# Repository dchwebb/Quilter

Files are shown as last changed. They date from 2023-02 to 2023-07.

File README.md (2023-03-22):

# Quilter
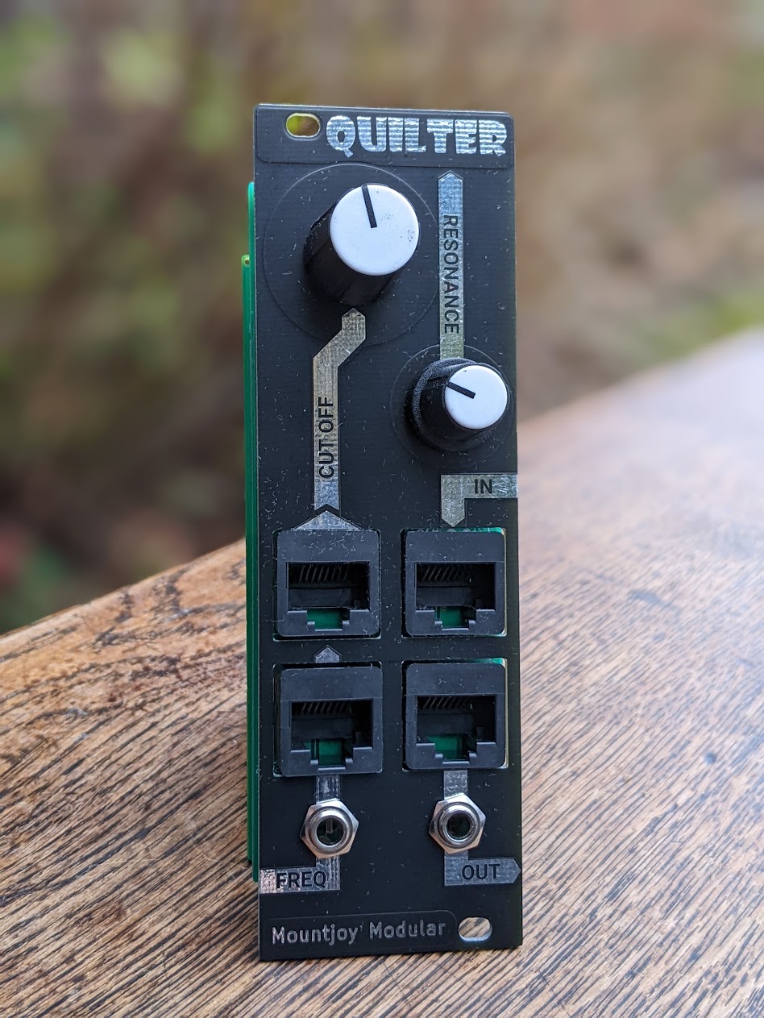
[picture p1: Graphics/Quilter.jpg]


Quilter
--------

Quilter is a four-voice polyphonic analog low pass filter designed for use with the Eurorack Modular Synthesiser architecture.

As part of a range of compatilble Mountjoy Modular modules, polyphonic interconnections are made using RJ-45 cables (as used for Ethernet).

Each of the four filters is a four-pole self-oscillating low pass filter. Cutoff is controlled by a combination of shared signals (frequency potentiometer and jack socket) and two individual  controls frequency controls (one at approximately half the sensitivity of the other) available on RJ-45 connectors.

Resonance is controlled from a potentiometer with self-oscillation available at extreme settings.

Polyphonic output is available from an RJ-45 socket and a mixed output is available on a 3.5mm jack socket.

The module is built around the Sound Semiconductor SSI2144 Fatkeys Four-Pole Voltage Controlled Filter. A number of TL074/TL072 op-amps are used for control signal mixing, buffering and output amplification.

Two trimmer potentiometers are available for each voice to control volt per octave when using the filter in self-resonant mode, and frequency offset to control the base frequency of the cut-off of each voice.

Technical
---------

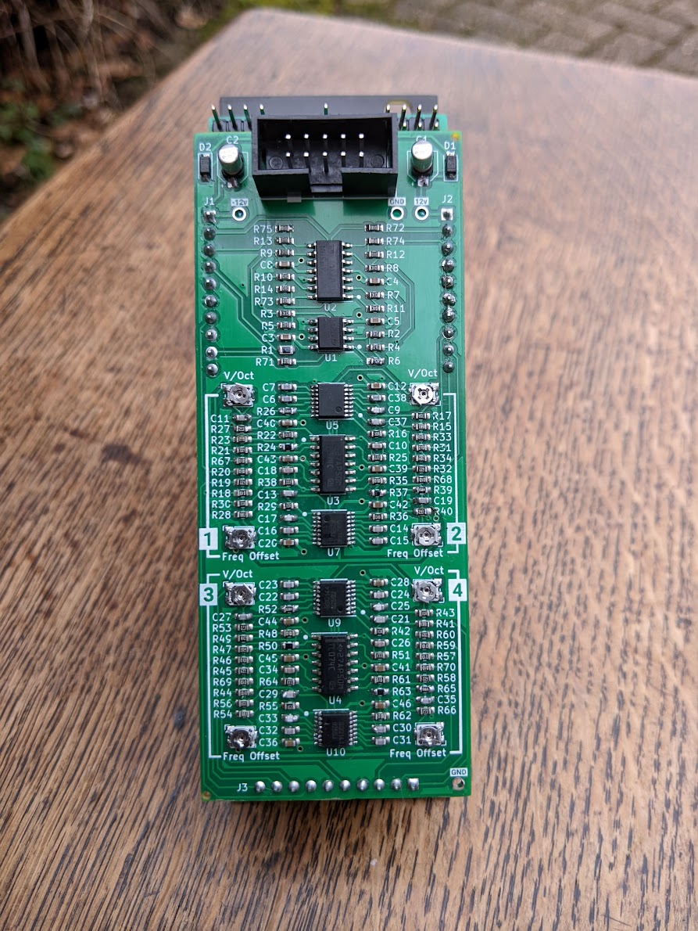
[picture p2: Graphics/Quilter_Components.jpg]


Construction is a sandwich of three PCBs with a component board, a controls board and a panel. PCBs designed in Kicad v6.

[Components schematic](https://raw.githubusercontent.com/dchwebb/Quilter/master/Quilter_Components.pdf)

[Controls schematic](https://raw.githubusercontent.com/dchwebb/Quilter/master/Quilter_Controls.pdf)

### Power

The Eurorack +/-12V rails have reverse polarity protection and filtering.

- +12V Current Draw: 52mA
- -12V Current Draw: 50mA

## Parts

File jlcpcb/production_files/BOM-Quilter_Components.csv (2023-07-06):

Comment | Designator | Footprint | LCSC
100pF | C10,C18,C26,C34 | C_0603_1608Metric_Pad1.08x0.95mm_HandSolder | C14858
1uF | C12,C20,C28,C3,C36,C39,C4,C40,C41,C42,C43,C44,C45,C46,C5,C8 | C_0603_1608Metric_Pad1.08x0.95mm_HandSolder | C15849
3.3nF | C13,C21,C29,C37 | C_0603_1608Metric_Pad1.08x0.95mm_HandSolder | C1613
6.8nF_C0G | C14,C15,C16,C22,C23,C24,C30,C31,C32,C38,C6,C7 | C_0603_1608Metric_Pad1.08x0.95mm_HandSolder | C162241
10uF | C47,C48,C49,C50 | C_0603_1608Metric_Pad1.08x0.95mm_HandSolder | C19702
1k | R23,R36,R49,R62,R71,R72,R73,R74,R75 | R_0603_1608Metric_Pad0.98x0.95mm_HandSolder | C21190
160k | R21,R34,R47,R60 | R_0603_1608Metric_Pad0.98x0.95mm_HandSolder | C22813
220k | R19,R32,R45,R58 | R_0603_1608Metric_Pad0.98x0.95mm_HandSolder | C22961
4.7k | R6 | R_0603_1608Metric_Pad0.98x0.95mm_HandSolder | C23162
68k | R15,R28,R41,R54 | R_0603_1608Metric_Pad0.98x0.95mm_HandSolder | C23231
24k | R27,R40,R53,R66 | R_0603_1608Metric_Pad0.98x0.95mm_HandSolder | C23352
100k | R18,R20,R22,R31,R33,R35,R44,R46,R48,R57,R59,R61,R67,R68,R69,R70 | R_0603_1608Metric_Pad0.98x0.95mm_HandSolder | C25803
10k | R10,R11,R12,R13,R14,R2,R3,R4,R5,R7,R8,R9 | R_0603_1608Metric_Pad0.98x0.95mm_HandSolder | C25804
33k | R25,R38,R51,R64 | R_0603_1608Metric_Pad0.98x0.95mm_HandSolder | C4216
10nF | C11,C19,C27,C35 | C_0603_1608Metric_Pad1.08x0.95mm_HandSolder | C57112
TL072 | U1 | SO-8_3.9x4.9mm_P1.27mm | C6961
200 | R16,R17,R29,R30,R42,R43,R55,R56 | R_0603_1608Metric_Pad0.98x0.95mm_HandSolder | C8218
1N5819 | D1,D2 | D_SOD-123 | C8598

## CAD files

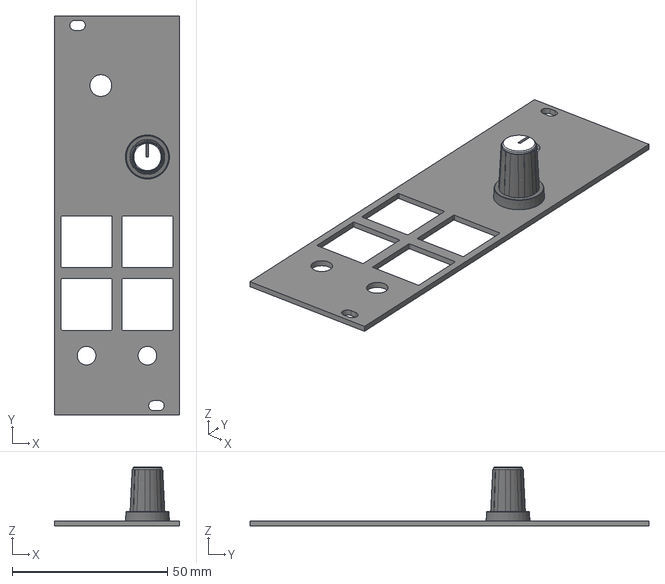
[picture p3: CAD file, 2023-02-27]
Graphics/Quilter_Panel.step
40.4 x 128.5 x 18.9 mm
_autosave-Quilter_Panel PCB

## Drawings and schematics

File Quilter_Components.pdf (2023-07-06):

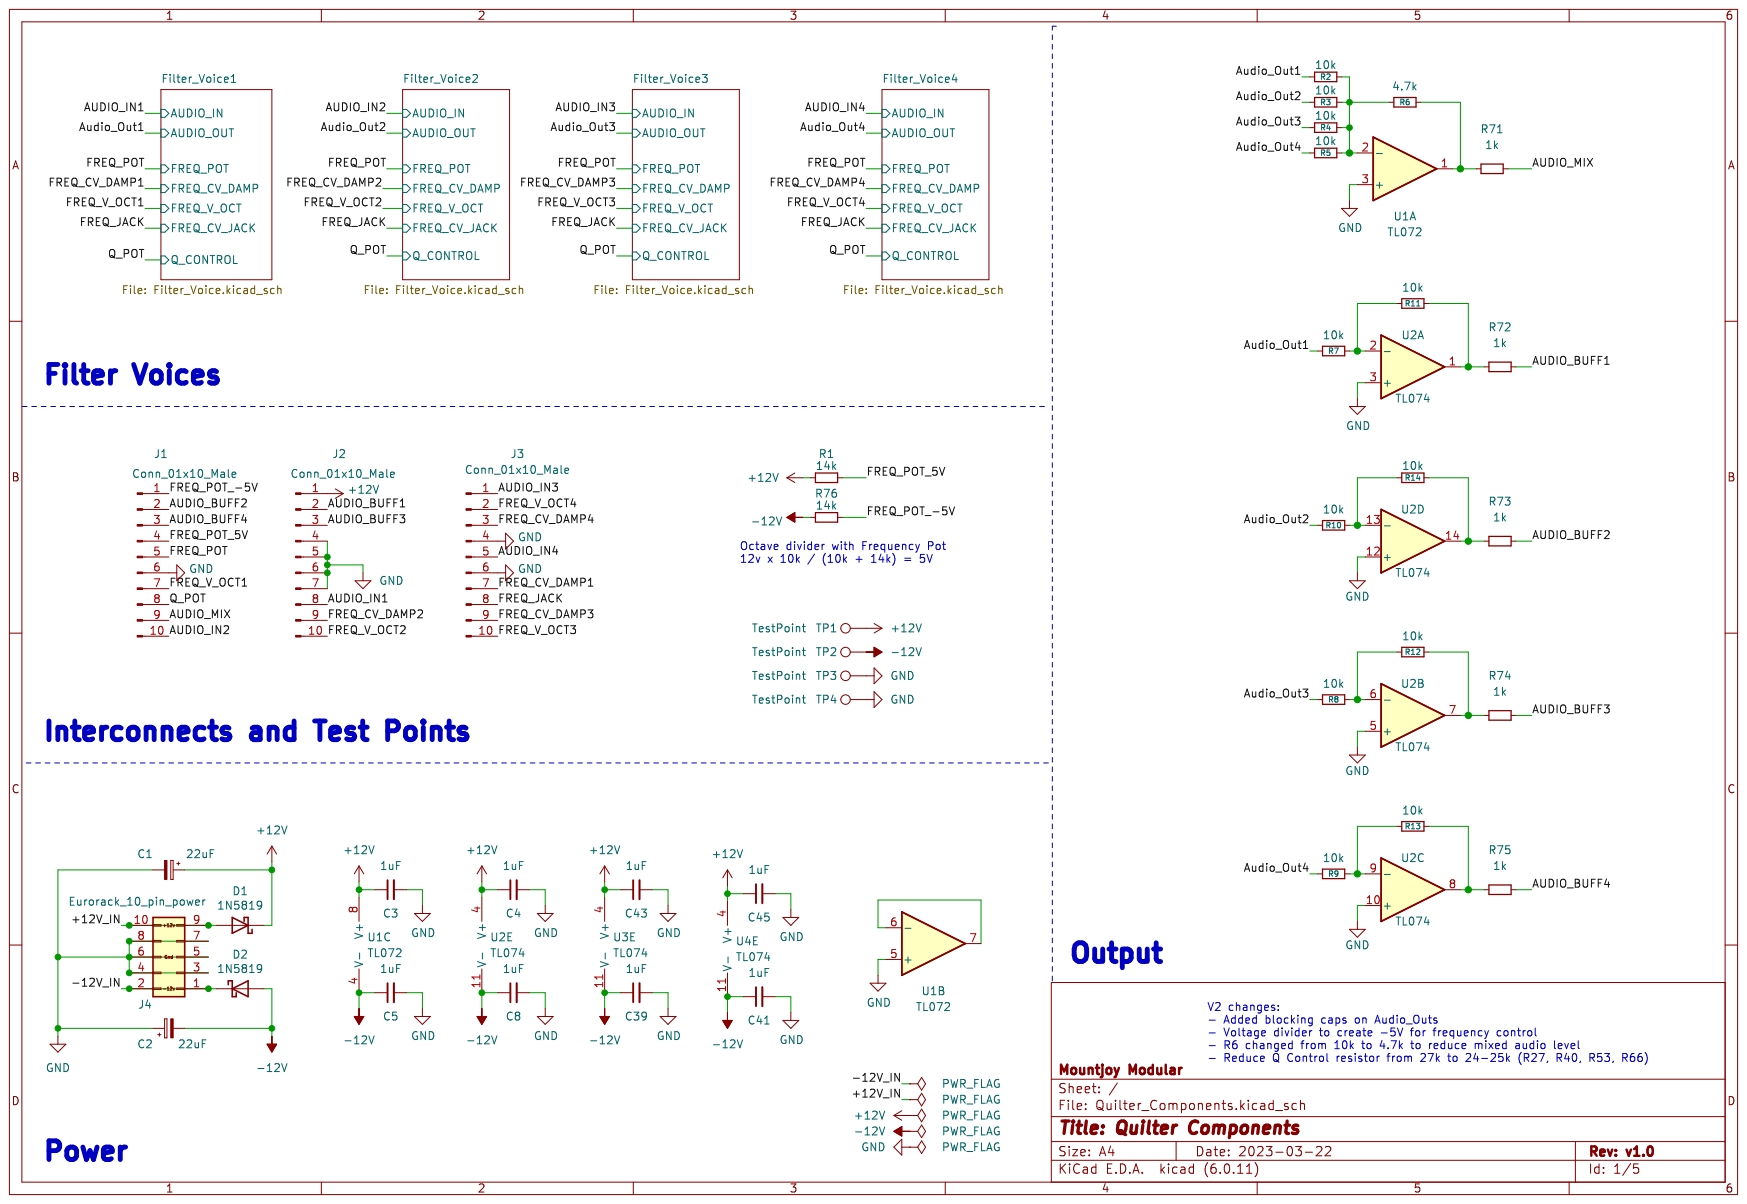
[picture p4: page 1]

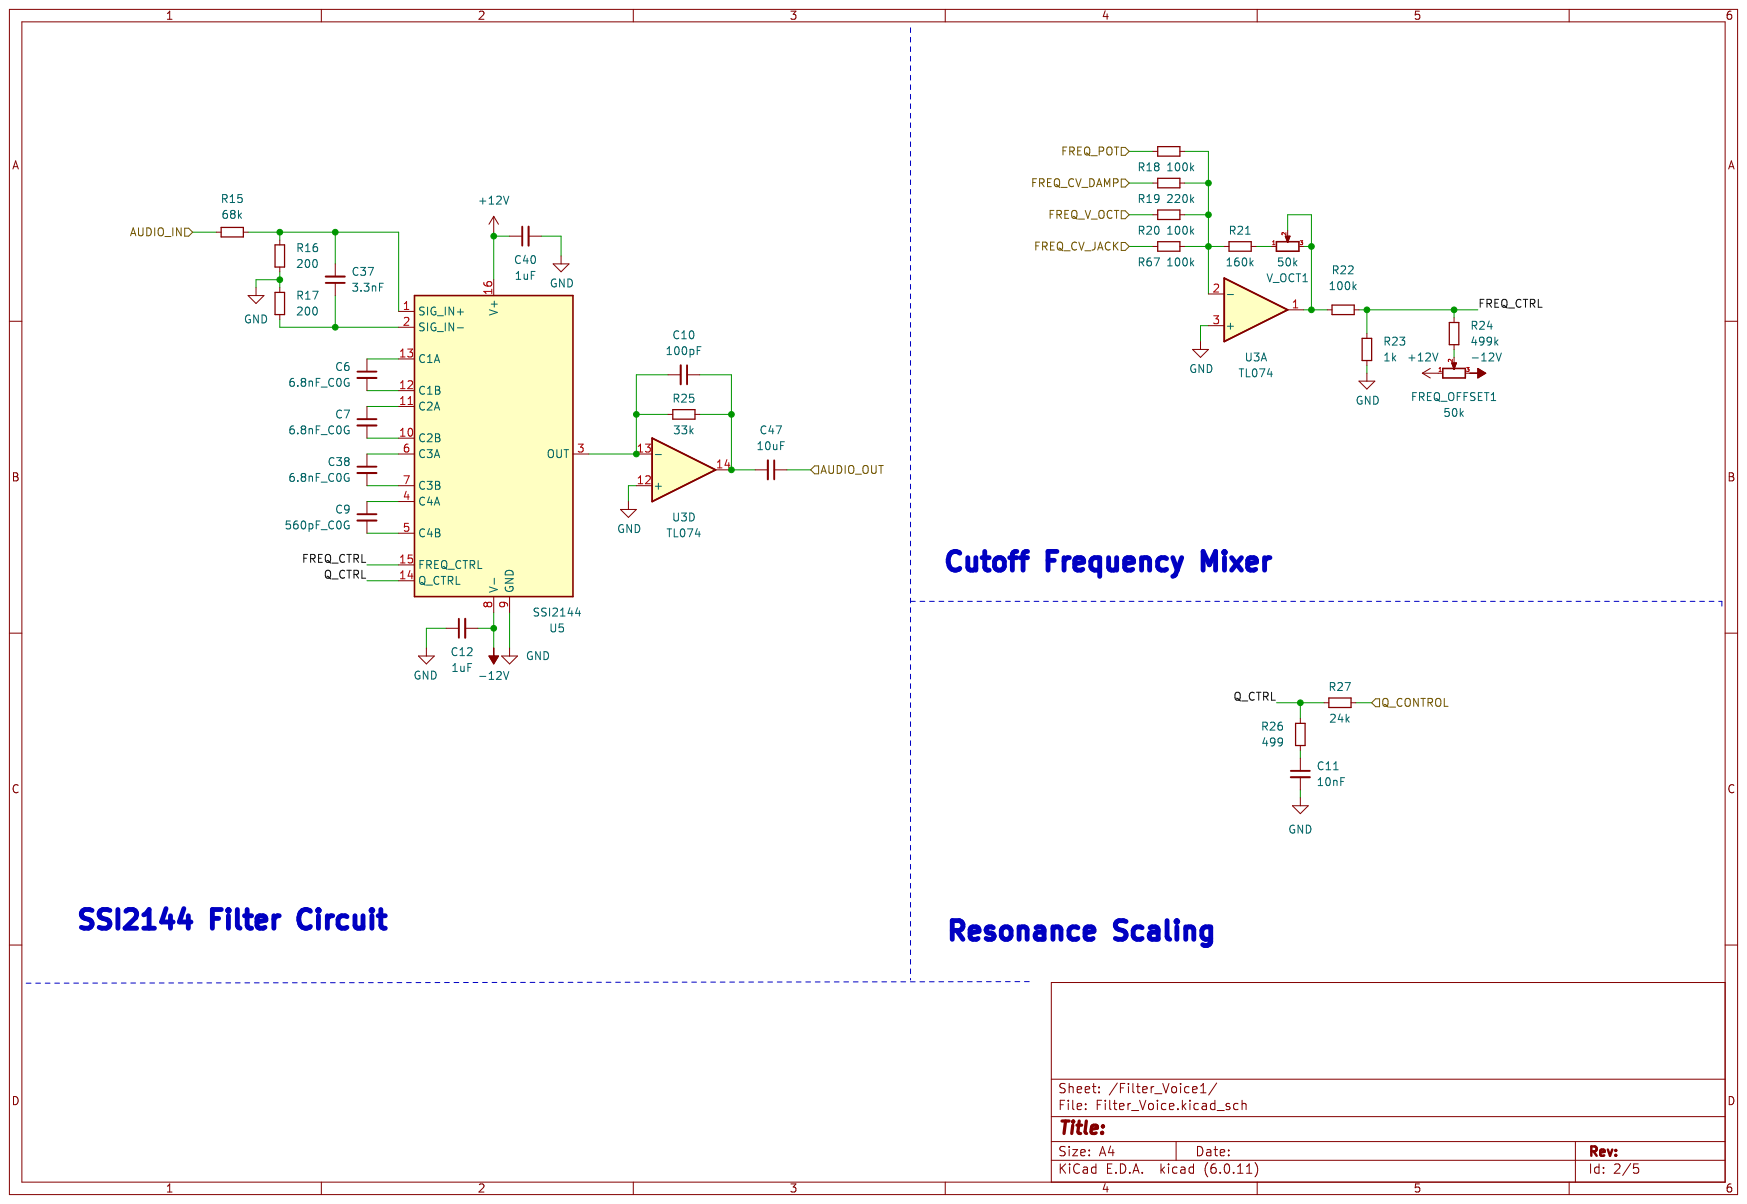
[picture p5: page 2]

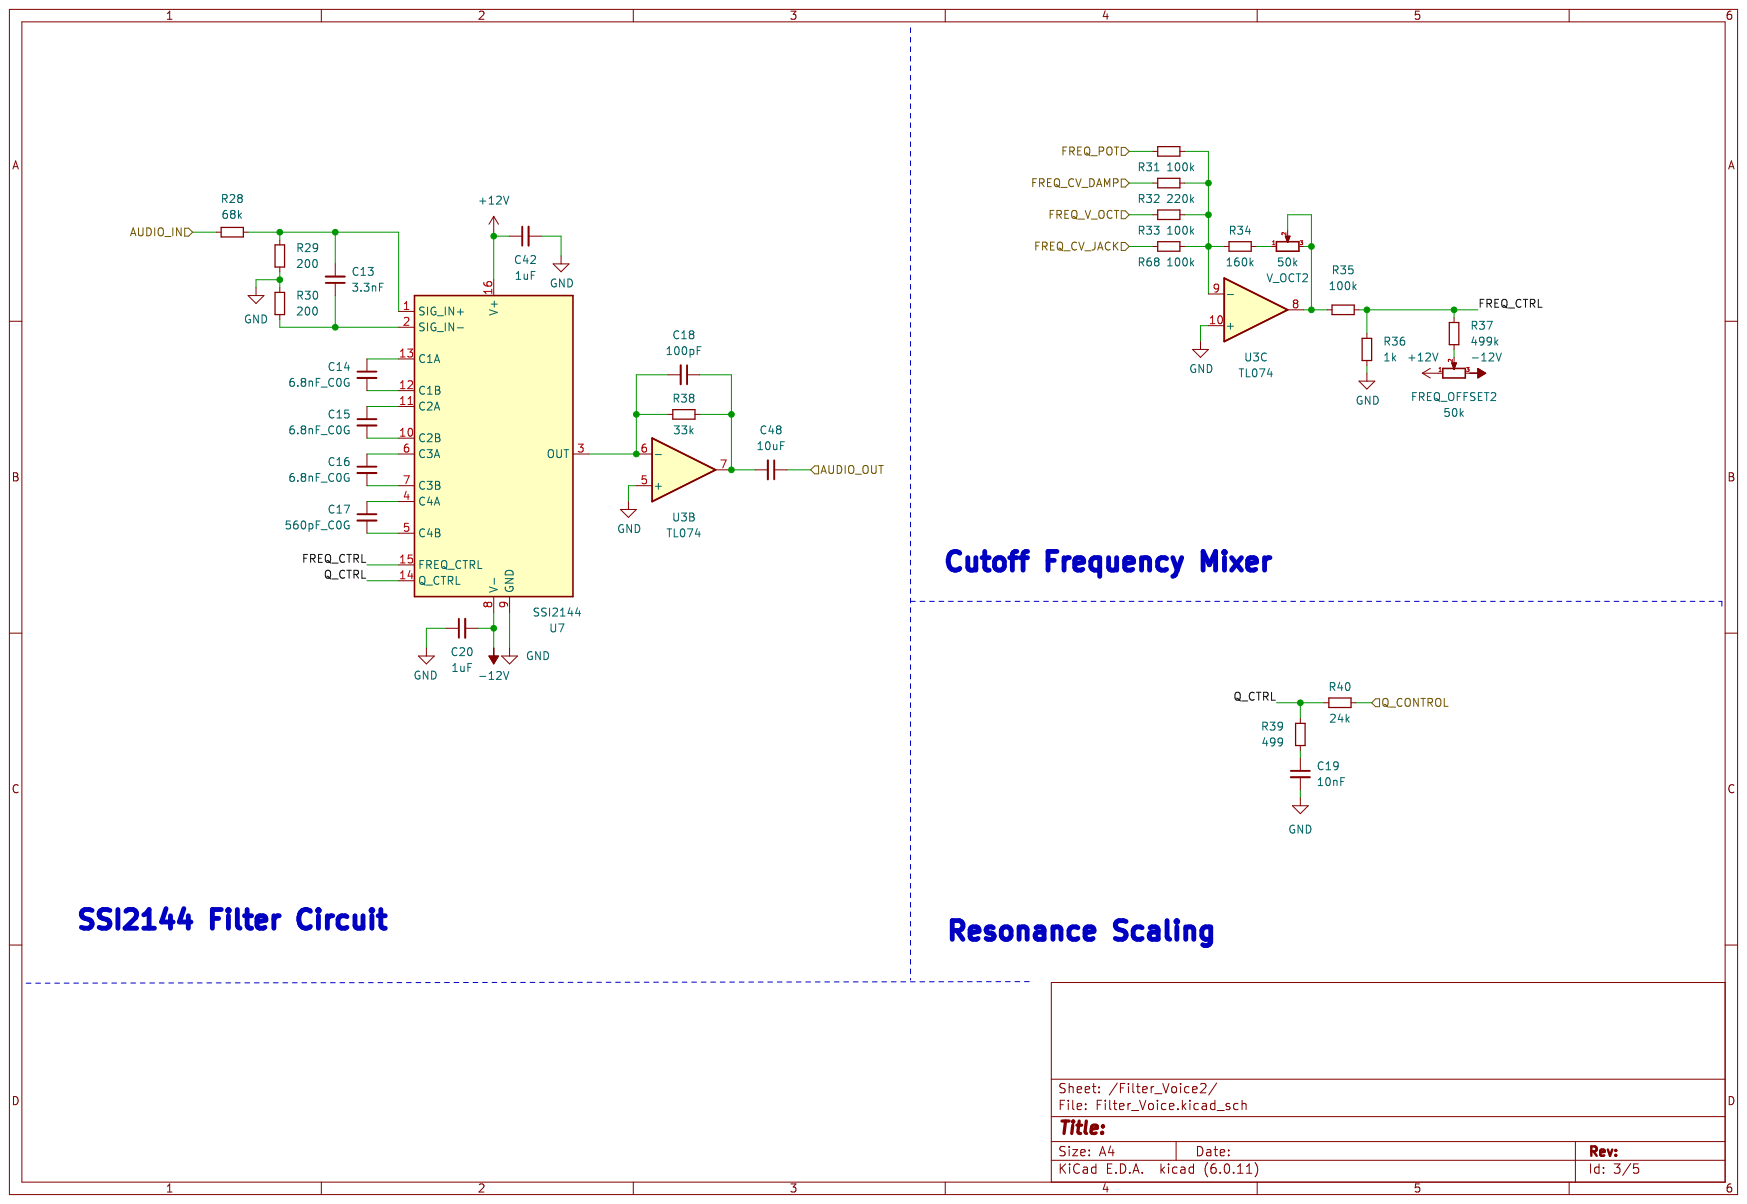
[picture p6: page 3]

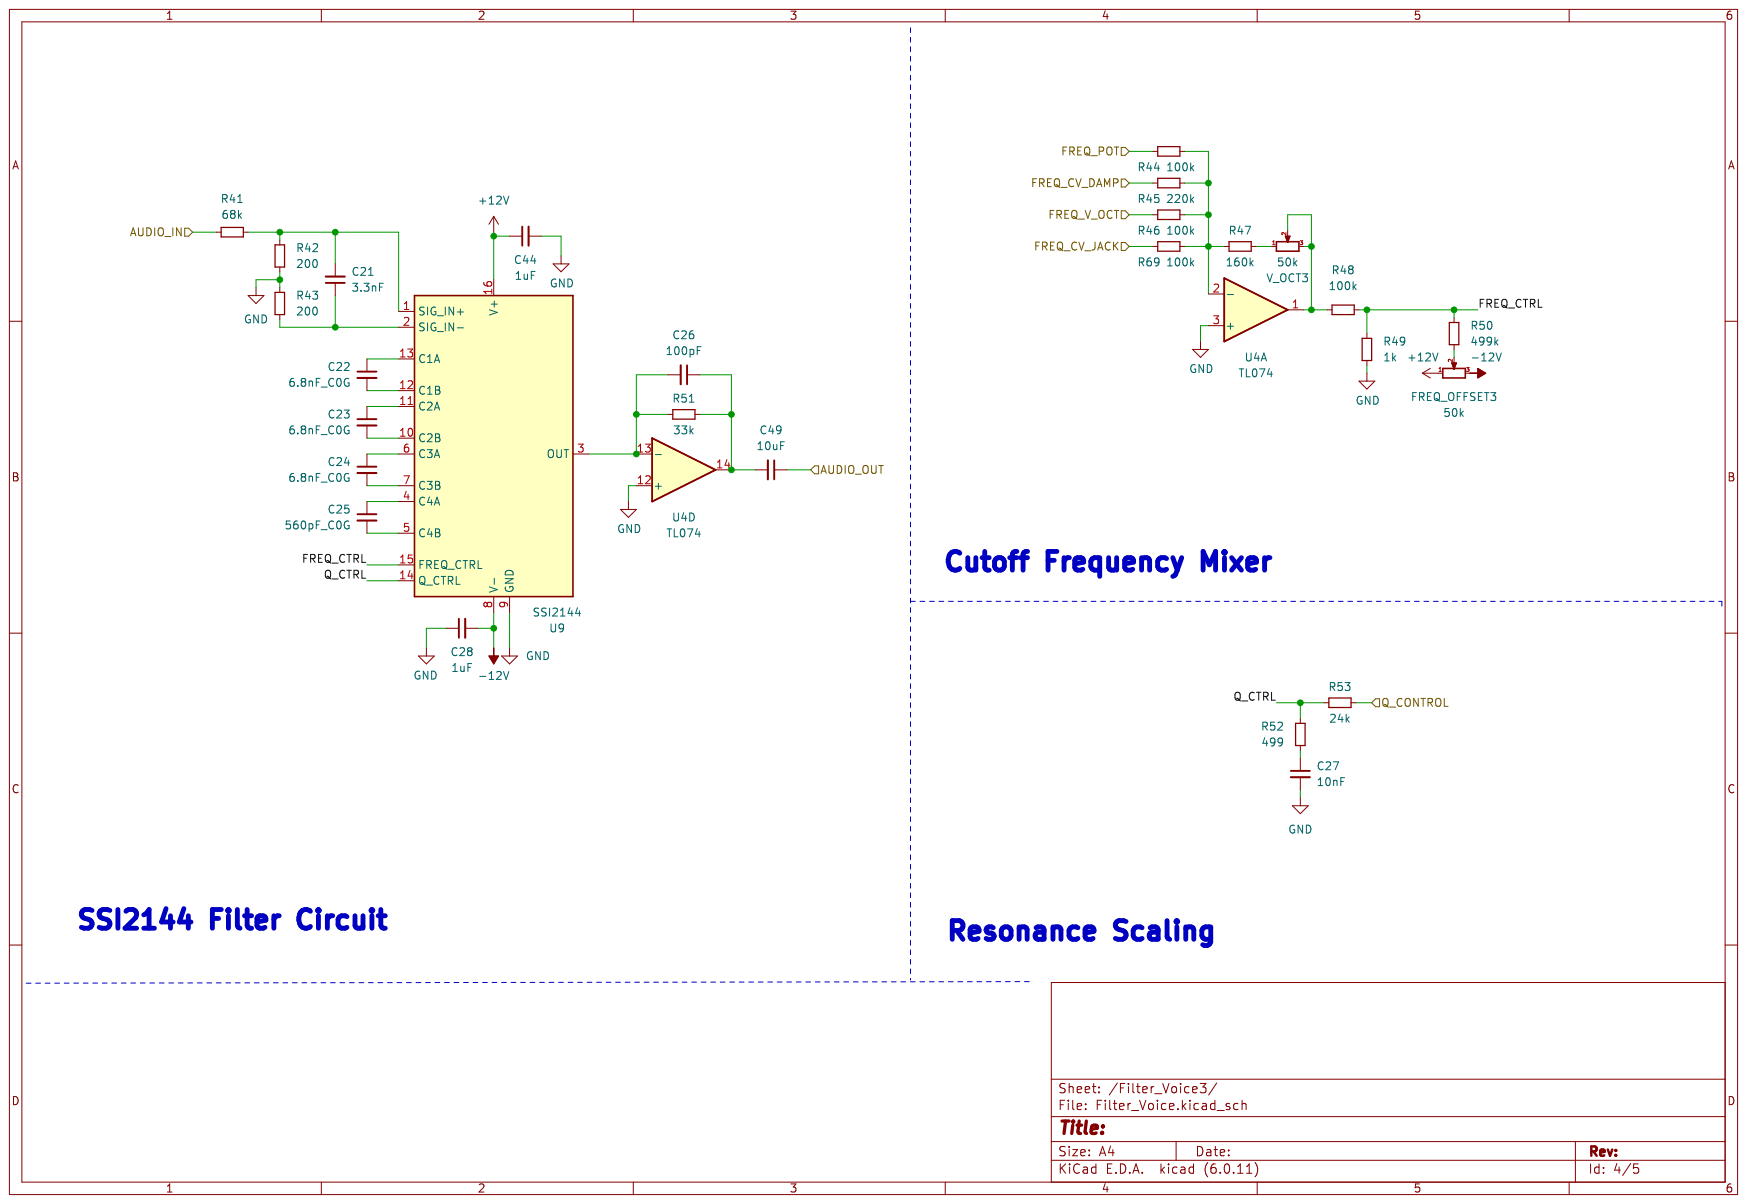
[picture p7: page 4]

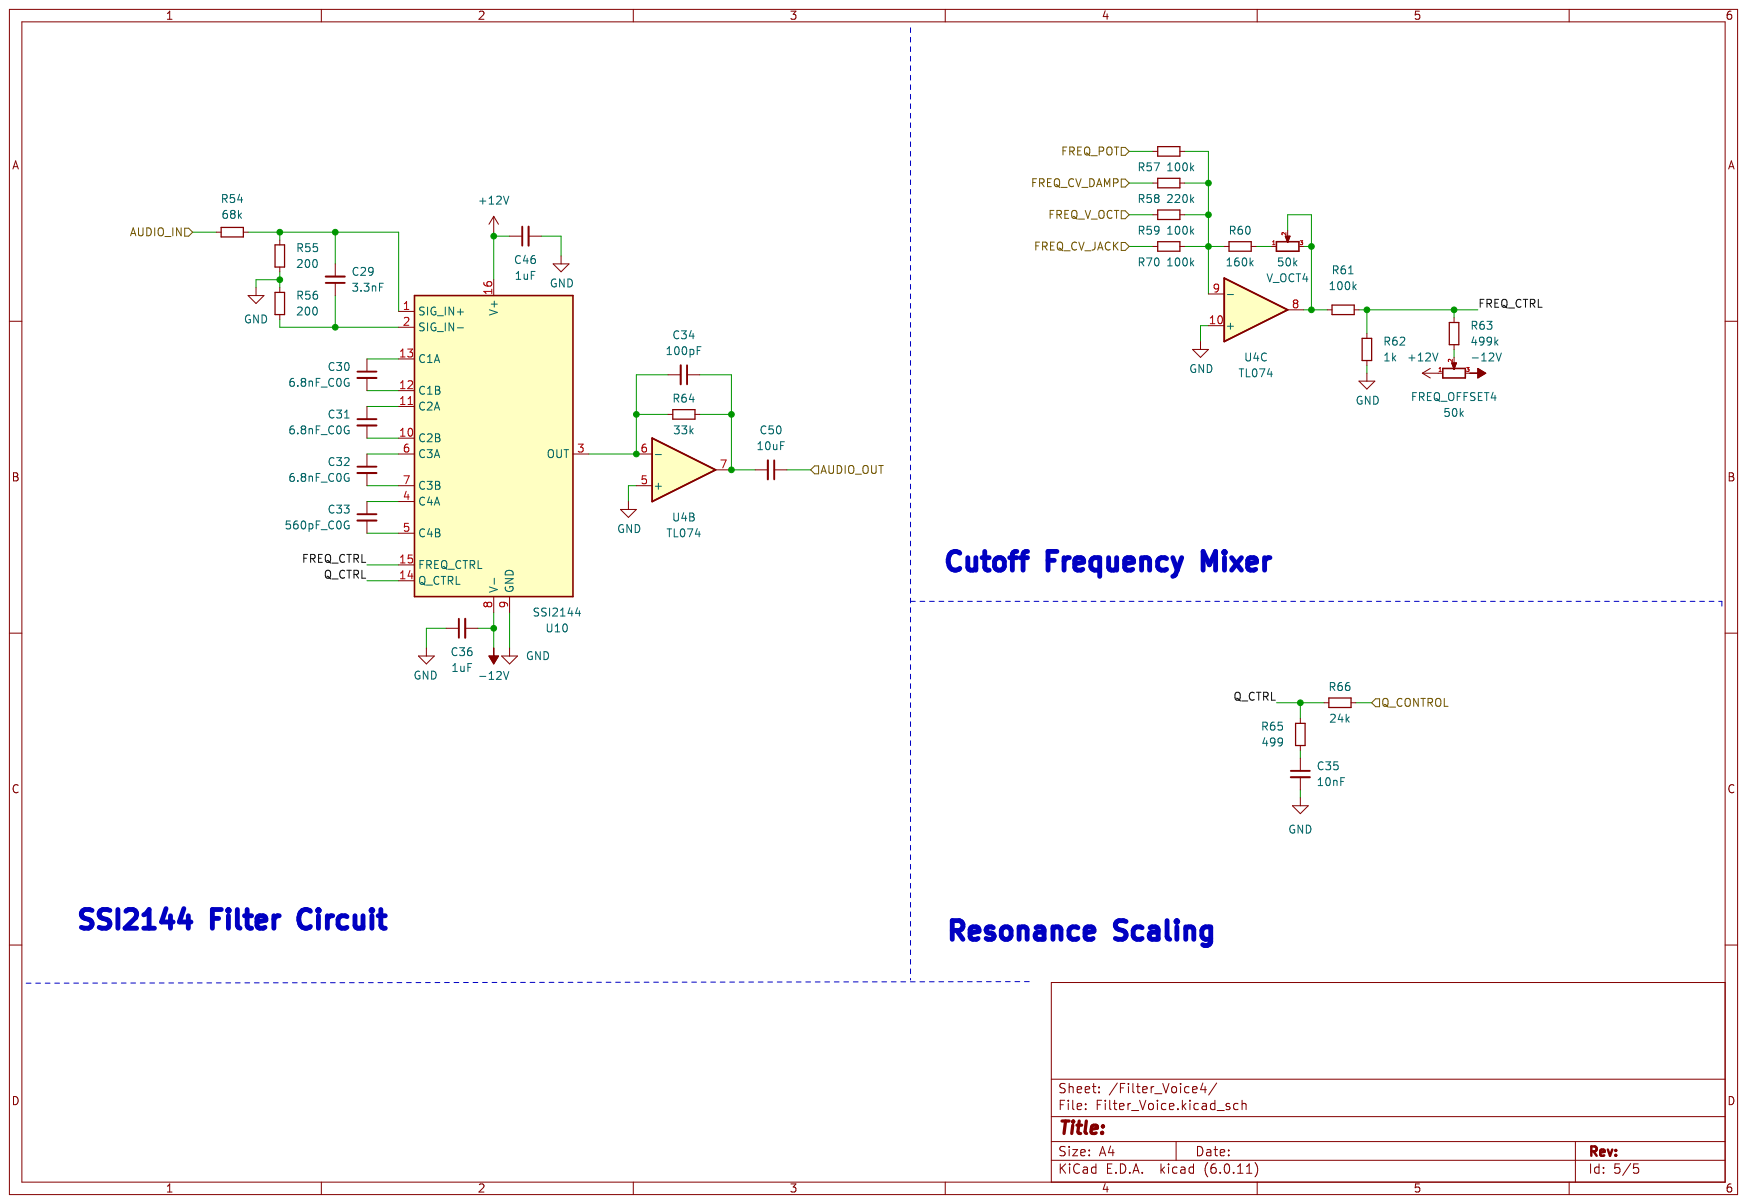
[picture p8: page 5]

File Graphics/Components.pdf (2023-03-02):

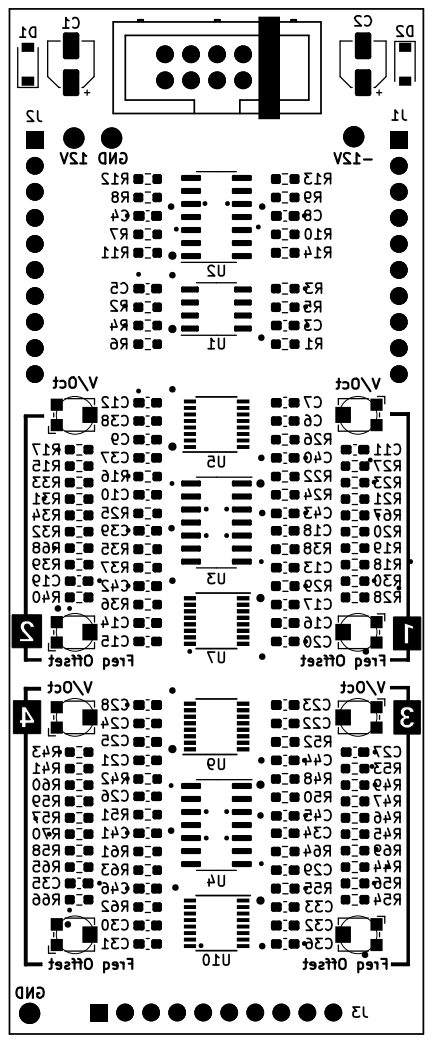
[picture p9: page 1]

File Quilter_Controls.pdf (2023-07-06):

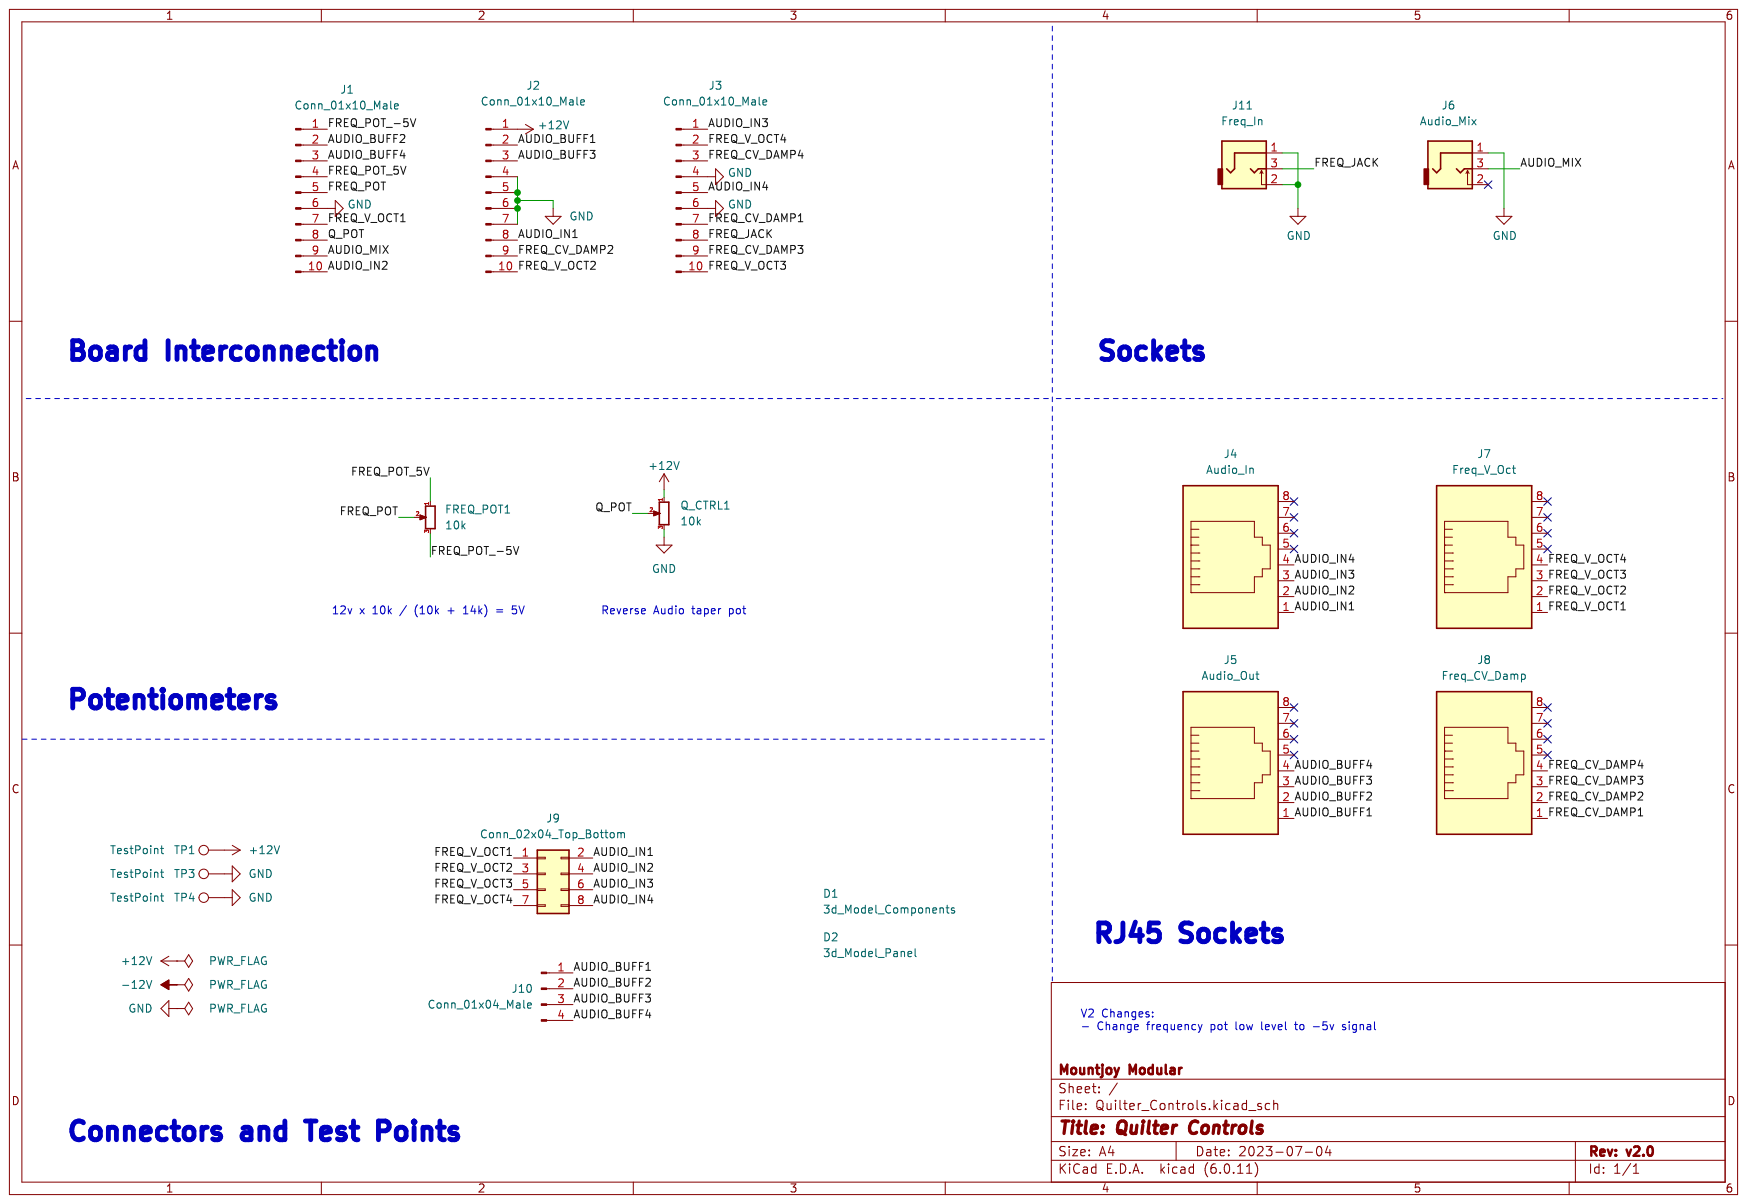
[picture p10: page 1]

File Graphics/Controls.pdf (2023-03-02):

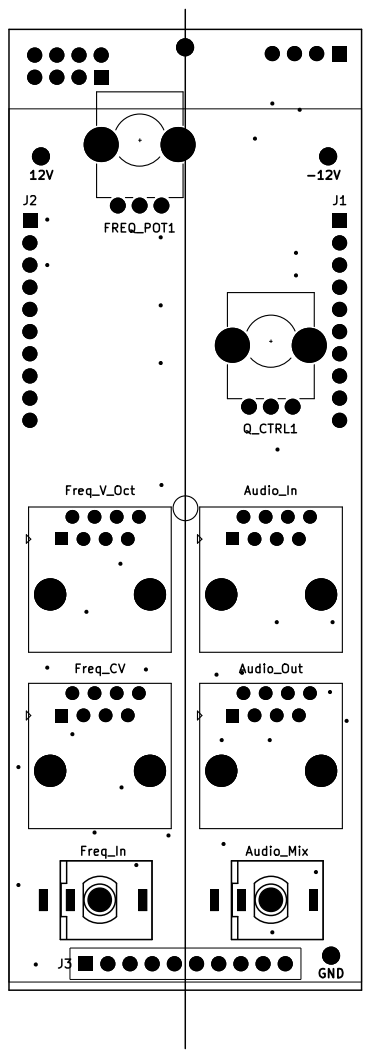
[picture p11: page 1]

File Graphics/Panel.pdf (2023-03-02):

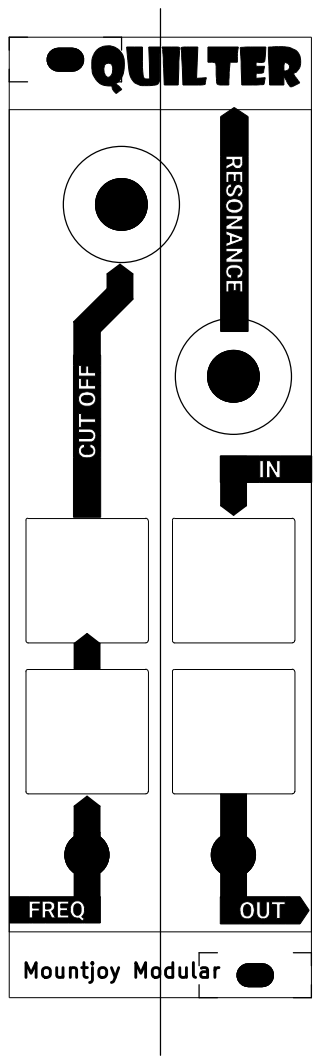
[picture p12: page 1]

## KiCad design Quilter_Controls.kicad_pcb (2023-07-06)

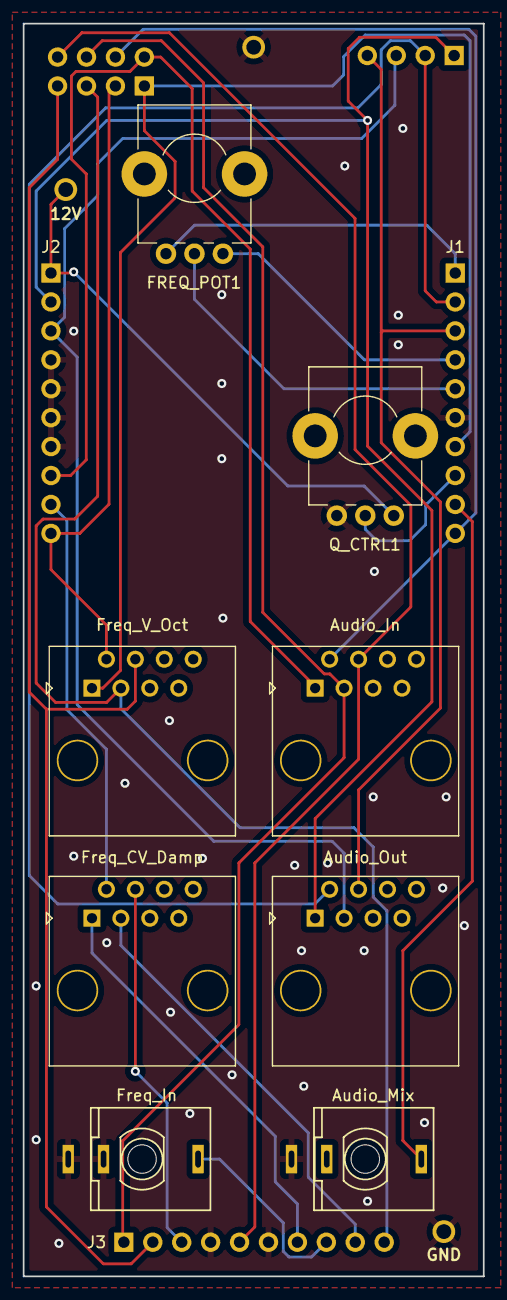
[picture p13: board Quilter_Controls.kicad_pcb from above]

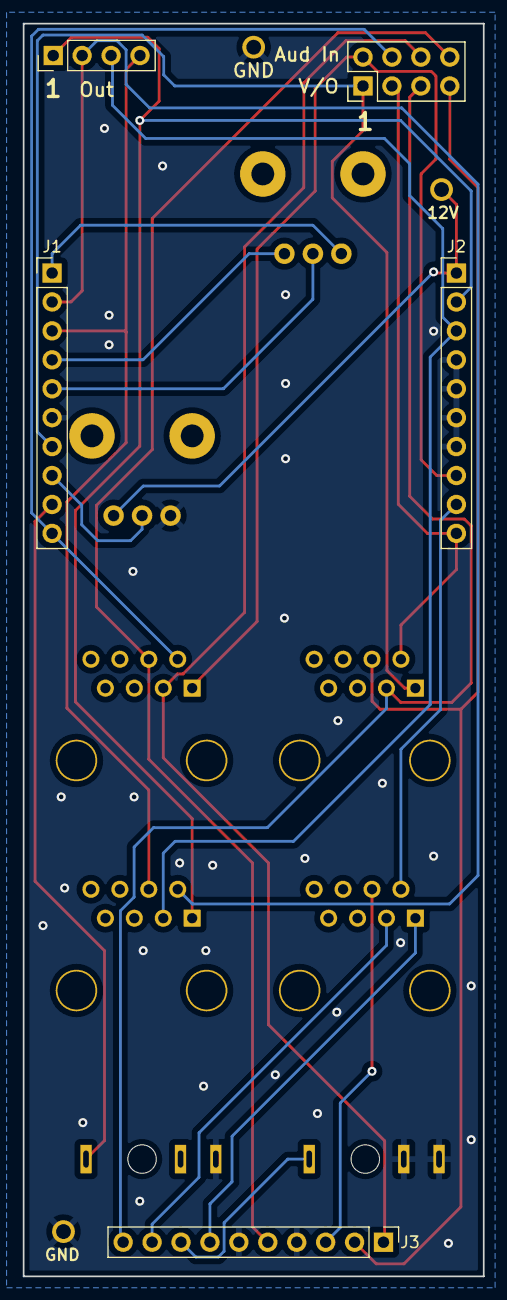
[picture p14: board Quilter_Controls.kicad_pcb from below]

Board: 2 copper layers, 40.4 x 110.0 mm, 16 parts (5 on the bottom side), 24 nets.

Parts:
FREQ_POT1: 10k; Alpha_9mm_Potentiometer_Aligned
J1, J2, J3: Conn_01x10_Male; PinHeader_1x10_P2.54mm_Vertical
J4: Audio_In; RJ45_Molex_42878-8506
J5: Audio_Out; RJ45_Molex_42878-8506
J6: Audio_Mix; THONKICONN_hole
J7: Freq_V_Oct; RJ45_Molex_42878-8506
J8: Freq_CV_Damp; RJ45_Molex_42878-8506
J9: Conn_02x04_Top_Bottom; PinHeader_2x04_P2.54mm_Vertical
J10: Conn_01x04_Male; PinHeader_1x04_P2.54mm_Vertical
J11: Freq_In; THONKICONN_hole
Q_CTRL1: 10k; Alpha_9mm_Potentiometer_Aligned
TP1, TP3, TP4: TestPoint; 1.3mm_Test_Point

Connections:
+12V: J2.1, Q_CTRL1.1, TP1.1
/AUDIO_BUFF1: J2.2, J5.1, J10.1
/AUDIO_BUFF2: J1.2, J5.2, J10.2
/AUDIO_BUFF3: J2.3, J5.3, J10.3
/AUDIO_BUFF4: J1.3, J5.4, J10.4
/AUDIO_IN1: J2.8, J4.1, J9.2
/AUDIO_IN2: J1.10, J4.2, J9.4
/AUDIO_IN3: J3.1, J4.3, J9.6
/AUDIO_IN4: J3.5, J4.4, J9.8
/AUDIO_MIX: J1.9, J6.3
/FREQ_CV_DAMP1: J3.7, J8.1
/FREQ_CV_DAMP2: J2.9, J8.2
/FREQ_CV_DAMP3: J3.9, J8.3
/FREQ_CV_DAMP4: J3.3, J8.4
/FREQ_JACK: J3.8, J11.3
/FREQ_POT: FREQ_POT1.2, J1.5
/FREQ_POT_5V: FREQ_POT1.1, J1.4
/FREQ_POT_-5V: FREQ_POT1.3, J1.1
/FREQ_V_OCT1: J1.7, J7.1, J9.1
/FREQ_V_OCT2: J2.10, J7.2, J9.3
/FREQ_V_OCT3: J3.10, J7.3, J9.5
/FREQ_V_OCT4: J3.2, J7.4, J9.7
/Q_POT: J1.8, Q_CTRL1.2
GND: J1.6, J2.4, J2.5, J2.6, J2.7, J3.4, J3.6, J6.1, J11.1, J11.2, Q_CTRL1.3, TP3.1, TP4.1

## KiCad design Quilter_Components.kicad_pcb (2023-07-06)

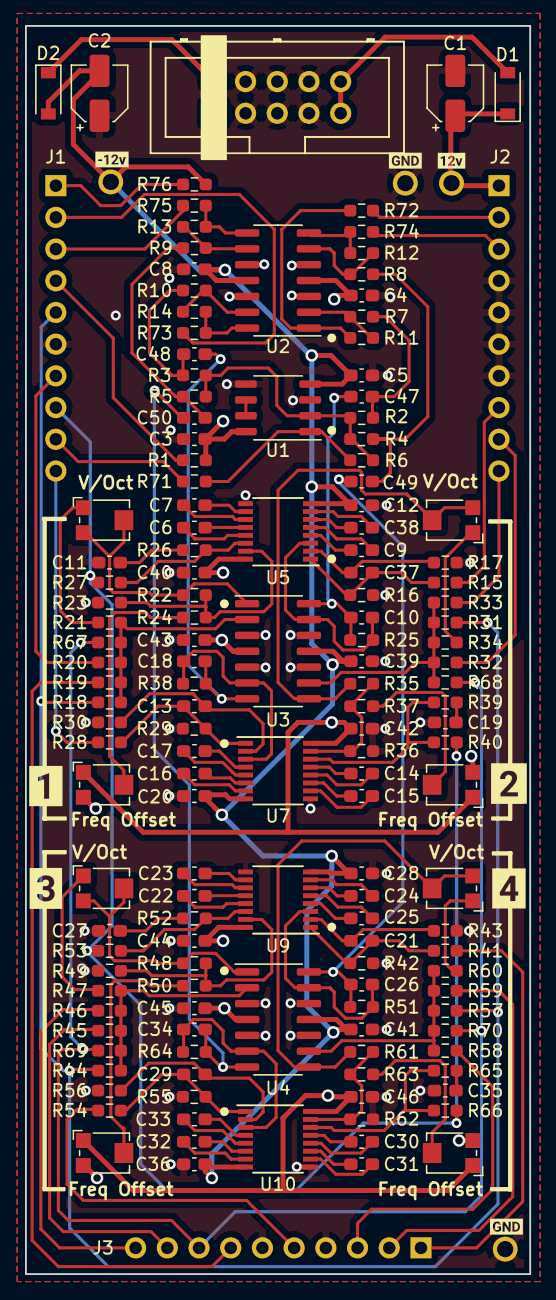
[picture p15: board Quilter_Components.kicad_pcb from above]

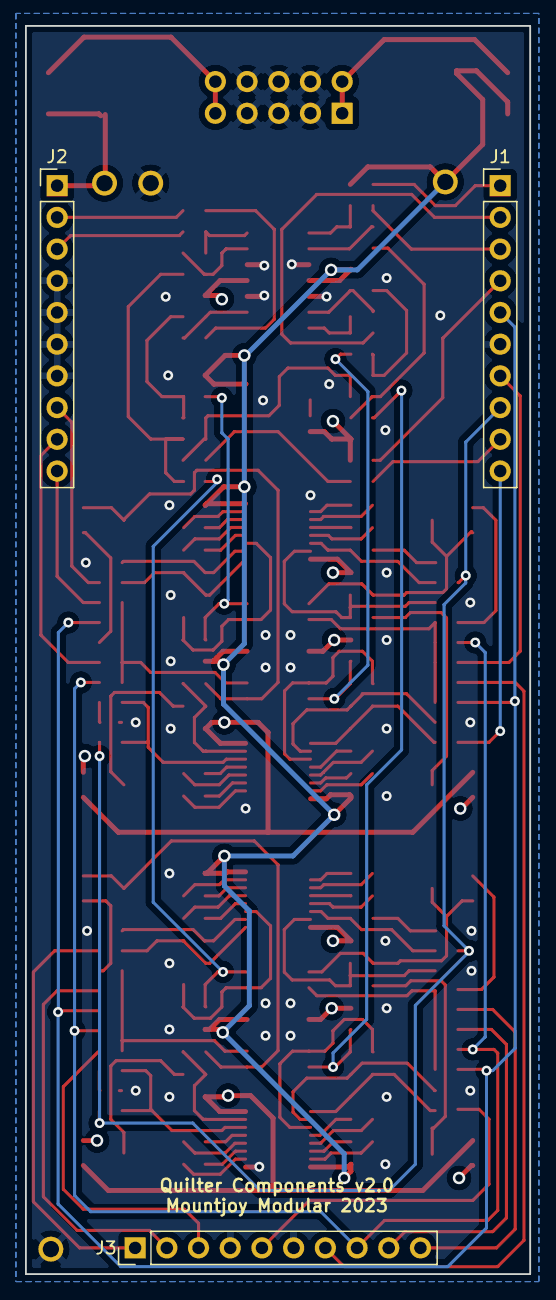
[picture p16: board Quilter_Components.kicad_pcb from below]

Board: 4 copper layers, 40.4 x 100.0 mm, 160 parts (3 on the bottom side), 118 nets.

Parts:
C1, C2: 22uF; CP_Elec_4x5.8
C3, C4, C5, C8, C12, C20, C28, C36, C39, C40, C41, C42, C43, C44, C45, C46: 1uF; C_0603_1608Metric_Pad1.08x0.95mm_HandSolder
C6, C7, C14, C15, C16, C22, C23, C24, C30, C31, C32, C38: 6.8nF_C0G; C_0603_1608Metric_Pad1.08x0.95mm_HandSolder
C9, C17, C25, C33: 560pF_C0G; C_0603_1608Metric_Pad1.08x0.95mm_HandSolder
C10, C18, C26, C34: 100pF; C_0603_1608Metric_Pad1.08x0.95mm_HandSolder
C11, C19, C27, C35: 10nF; C_0603_1608Metric_Pad1.08x0.95mm_HandSolder
C13, C21, C29, C37: 3.3nF; C_0603_1608Metric_Pad1.08x0.95mm_HandSolder
C47, C48, C49, C50: 10uF; C_0603_1608Metric_Pad1.08x0.95mm_HandSolder
D1, D2: 1N5819; D_SOD-123
FREQ_OFFSET1, FREQ_OFFSET2, FREQ_OFFSET3, FREQ_OFFSET4: 50k; Potentiometer_Bourns_TC33X_Vertical
J1, J2, J3: Conn_01x10_Male; PinHeader_1x10_P2.54mm_Vertical
J4: Eurorack_10_pin_power; Eurorack_10_pin_header
R1, R76: 14k; R_0603_1608Metric_Pad0.98x0.95mm_HandSolder
R2, R3, R4, R5, R7, R8, R9, R10, R11, R12, R13, R14: 10k; R_0603_1608Metric_Pad0.98x0.95mm_HandSolder
R6: 4.7k; R_0603_1608Metric_Pad0.98x0.95mm_HandSolder
R15, R28, R41, R54: 68k; R_0603_1608Metric_Pad0.98x0.95mm_HandSolder
R16, R17, R29, R30, R42, R43, R55, R56: 200; R_0603_1608Metric_Pad0.98x0.95mm_HandSolder
R18, R20, R22, R31, R33, R35, R44, R46, R48, R57, R59, R61, R67, R68, R69, R70: 100k; R_0603_1608Metric_Pad0.98x0.95mm_HandSolder
R19, R32, R45, R58: 220k; R_0603_1608Metric_Pad0.98x0.95mm_HandSolder
R21, R34, R47, R60: 160k; R_0603_1608Metric_Pad0.98x0.95mm_HandSolder
R23, R36, R49, R62, R71, R72, R73, R74, R75: 1k; R_0603_1608Metric_Pad0.98x0.95mm_HandSolder
R24, R37, R50, R63: 499k; R_0603_1608Metric_Pad0.98x0.95mm_HandSolder
R25, R38, R51, R64: 33k; R_0603_1608Metric_Pad0.98x0.95mm_HandSolder
R26, R39, R52, R65: 499; R_0603_1608Metric_Pad0.98x0.95mm_HandSolder
R27, R40, R53, R66: 24k; R_0603_1608Metric_Pad0.98x0.95mm_HandSolder
TP1, TP2, TP3, TP4: TestPoint; 1.3mm_Test_Point
U1: TL072; SO-8_3.9x4.9mm_P1.27mm
U2, U3, U4: TL074; SOIC-14_3.9x8.7mm_P1.27mm
U5, U7, U9, U10: SSI2144; SSOP-16_3.9x4.9mm_P0.635mm
V_OCT1, V_OCT2, V_OCT3, V_OCT4: 50k; Potentiometer_Bourns_TC33X_Vertical
kibuzzard-63F9EC4B: G***; kibuzzard-63F9EC4B
kibuzzard-63F9ECEE: G***; kibuzzard-63F9ECEE
kibuzzard-63FCE890: G***; kibuzzard-63FCE890
kibuzzard-63FCEF0D: G***; kibuzzard-63FCEF0D
kibuzzard-640237A8: G***; kibuzzard-640237A8
kibuzzard-640237DF, kibuzzard-640237DF#2: G***; kibuzzard-640237DF
kibuzzard-640237FD: G***; kibuzzard-640237FD

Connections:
+12V: C1.1, C3.1, C4.1, C40.1, C42.1, C43.1, C44.1, C45.1, C46.1, D1.1 (K), FREQ_OFFSET1.1, FREQ_OFFSET2.1, FREQ_OFFSET3.1, FREQ_OFFSET4.1, J2.1, R1.1, TP1.1, U1.8 (V+), U2.4 (V+), U3.4 (V+), U4.4 (V+), U5.16 (V+), U7.16 (V+), U9.16 (V+), U10.16 (V+)
-12V: C2.2, C5.1, C8.1, C12.2, C20.2, C28.2, C36.2, C39.1, C41.1, D2.2 (A), FREQ_OFFSET1.3, FREQ_OFFSET2.3, FREQ_OFFSET3.3, FREQ_OFFSET4.3, R76.1, TP2.1, U1.4 (V-), U2.11 (V-), U3.11 (V-), U4.11 (V-), U5.8 (V-), U7.8 (V-), U9.8 (V-), U10.8 (V-)
/+12V_IN: D1.2 (A), J4.9, J4.10
/-12V_IN: D2.1 (K), J4.1, J4.2
/AUDIO_BUFF1: J2.2, R72.2
/AUDIO_BUFF2: J1.2, R73.2
/AUDIO_BUFF3: J2.3, R74.2
/AUDIO_BUFF4: J1.3, R75.2
/AUDIO_IN1: J2.8, R15.2
/AUDIO_IN2: J1.10, R28.2
/AUDIO_IN3: J3.1, R41.2
/AUDIO_IN4: J3.5, R54.2
/AUDIO_MIX: J1.9, R71.2
/Audio_Out1: C47.1, R2.2, R7.2
/Audio_Out2: C48.1, R3.2, R10.2
/Audio_Out3: C49.1, R4.2, R8.2
/Audio_Out4: C50.1, R5.2, R9.2
/FREQ_CV_DAMP1: J3.7, R19.2
/FREQ_CV_DAMP2: J2.9, R32.2
/FREQ_CV_DAMP3: J3.9, R45.2
/FREQ_CV_DAMP4: J3.3, R58.2
/FREQ_JACK: J3.8, R67.2, R68.2, R69.2, R70.2
/FREQ_POT: J1.5, R18.2, R31.2, R44.2, R57.2
/FREQ_POT_5V: J1.4, R1.2
/FREQ_POT_-5V: J1.1, R76.2
/FREQ_V_OCT1: J1.7, R20.2
/FREQ_V_OCT2: J2.10, R33.2
/FREQ_V_OCT3: J3.10, R46.2
/FREQ_V_OCT4: J3.2, R59.2
/Filter_Voice1/FREQ_CTRL: R22.1, R23.1, R24.1, U5.15 (FREQ_CTRL)
/Filter_Voice1/Q_CTRL: R26.2, R27.2, U5.14 (Q_CTRL)
/Filter_Voice2/FREQ_CTRL: R35.1, R36.1, R37.1, U7.15 (FREQ_CTRL)
/Filter_Voice2/Q_CTRL: R39.2, R40.2, U7.14 (Q_CTRL)
/Filter_Voice3/FREQ_CTRL: R48.1, R49.1, R50.1, U9.15 (FREQ_CTRL)
/Filter_Voice3/Q_CTRL: R52.2, R53.2, U9.14 (Q_CTRL)
/Filter_Voice4/FREQ_CTRL: R61.1, R62.1, R63.1, U10.15 (FREQ_CTRL)
/Filter_Voice4/Q_CTRL: R65.2, R66.2, U10.14 (Q_CTRL)
/Q_POT: J1.8, R27.1, R40.1, R53.1, R66.1
GND: C1.2, C2.1, C3.2, C4.2, C5.2, C8.2, C11.2, C12.1, C19.2, C20.1, C27.2, C28.1, C35.2, C36.1, C39.2, C40.2, C41.2, C42.2, C43.2, C44.2, C45.2, C46.2, J1.6, J2.4, J2.5, J2.6, J2.7, J3.4, J3.6, J4.3, J4.4, J4.5, J4.6, J4.7, J4.8, R16.1, R17.2, R23.2, R29.1, R30.2, R36.2, R42.1, R43.2, R49.2, R55.1, R56.2, R62.2, TP3.1, TP4.1, U1.3 (+), U1.5 (+), U2.3 (+), U2.5 (+), U2.10 (+), U2.12 (+), U3.3 (+), U3.5 (+), U3.10 (+), U3.12 (+), U4.3 (+), U4.5 (+), U4.10 (+), U4.12 (+), U5.9 (GND), U7.9 (GND), U9.9 (GND), U10.9 (GND)
unnamed: C6.1, U5.13 (C1A)
unnamed: C6.2, U5.12 (C1B)
unnamed: C7.1, U5.11 (C2A)
unnamed: C7.2, U5.10 (C2B)
unnamed: C9.1, U5.4 (C4A)
unnamed: C9.2, U5.5 (C4B)
unnamed: C10.1, C47.2, R25.1, U3.14
unnamed: C10.2, R25.2, U3.13 (-), U5.3 (OUT)
unnamed: C11.1, R26.1
unnamed: C13.1, R30.1, U7.2 (SIG_IN-)
unnamed: C13.2, R28.1, R29.2, U7.1 (SIG_IN+)
unnamed: C14.1, U7.13 (C1A)
unnamed: C14.2, U7.12 (C1B)
unnamed: C15.1, U7.11 (C2A)
unnamed: C15.2, U7.10 (C2B)
unnamed: C16.1, U7.6 (C3A)
unnamed: C16.2, U7.7 (C3B)
unnamed: C17.1, U7.4 (C4A)
unnamed: C17.2, U7.5 (C4B)
unnamed: C18.1, C48.2, R38.1, U3.7
unnamed: C18.2, R38.2, U3.6 (-), U7.3 (OUT)
unnamed: C19.1, R39.1
unnamed: C21.1, R43.1, U9.2 (SIG_IN-)
unnamed: C21.2, R41.1, R42.2, U9.1 (SIG_IN+)
unnamed: C22.1, U9.13 (C1A)
unnamed: C22.2, U9.12 (C1B)
unnamed: C23.1, U9.11 (C2A)
unnamed: C23.2, U9.10 (C2B)
unnamed: C24.1, U9.6 (C3A)
unnamed: C24.2, U9.7 (C3B)
unnamed: C25.1, U9.4 (C4A)
unnamed: C25.2, U9.5 (C4B)
unnamed: C26.1, C49.2, R51.1, U4.14
unnamed: C26.2, R51.2, U4.13 (-), U9.3 (OUT)
unnamed: C27.1, R52.1
unnamed: C29.1, R56.1, U10.2 (SIG_IN-)
unnamed: C29.2, R54.1, R55.2, U10.1 (SIG_IN+)
unnamed: C30.1, U10.13 (C1A)
unnamed: C30.2, U10.12 (C1B)
unnamed: C31.1, U10.11 (C2A)
unnamed: C31.2, U10.10 (C2B)
unnamed: C32.1, U10.6 (C3A)
unnamed: C32.2, U10.7 (C3B)
unnamed: C33.1, U10.4 (C4A)
unnamed: C33.2, U10.5 (C4B)
unnamed: C34.1, C50.2, R64.1, U4.7
unnamed: C34.2, R64.2, U4.6 (-), U10.3 (OUT)
unnamed: C35.1, R65.1
unnamed: C37.1, R17.1, U5.2 (SIG_IN-)
unnamed: C37.2, R15.1, R16.2, U5.1 (SIG_IN+)
unnamed: C38.1, U5.6 (C3A)
unnamed: C38.2, U5.7 (C3B)
unnamed: FREQ_OFFSET1.2, R24.2
unnamed: FREQ_OFFSET2.2, R37.2
unnamed: FREQ_OFFSET3.2, R50.2
unnamed: FREQ_OFFSET4.2, R63.2
unnamed: R2.1, R3.1, R4.1, R5.1, R6.2, U1.2 (-)
unnamed: R6.1, R71.1, U1.1
unnamed: R10.1, R14.2, U2.13 (-)
unnamed: R11.1, R72.1, U2.1
unnamed: R7.1, R11.2, U2.2 (-)
unnamed: R12.1, R74.1, U2.7
unnamed: R8.1, R12.2, U2.6 (-)
unnamed: R13.1, R75.1, U2.8
unnamed: R9.1, R13.2, U2.9 (-)
unnamed: R14.1, R73.1, U2.14
unnamed: R18.1, R19.1, R20.1, R21.2, R67.1, U3.2 (-)
unnamed: R21.1, V_OCT1.1
unnamed: R22.2, U3.1, V_OCT1.2, V_OCT1.3
unnamed: R31.1, R32.1, R33.1, R34.2, R68.1, U3.9 (-)
unnamed: R34.1, V_OCT2.1
unnamed: R35.2, U3.8, V_OCT2.2, V_OCT2.3
unnamed: R44.1, R45.1, R46.1, R47.2, R69.1, U4.2 (-)
unnamed: R47.1, V_OCT3.1
unnamed: R48.2, U4.1, V_OCT3.2, V_OCT3.3
unnamed: R57.1, R58.1, R59.1, R60.2, R70.1, U4.9 (-)
unnamed: R60.1, V_OCT4.1
unnamed: R61.2, U4.8, V_OCT4.2, V_OCT4.3
unnamed: U1.6 (-), U1.7

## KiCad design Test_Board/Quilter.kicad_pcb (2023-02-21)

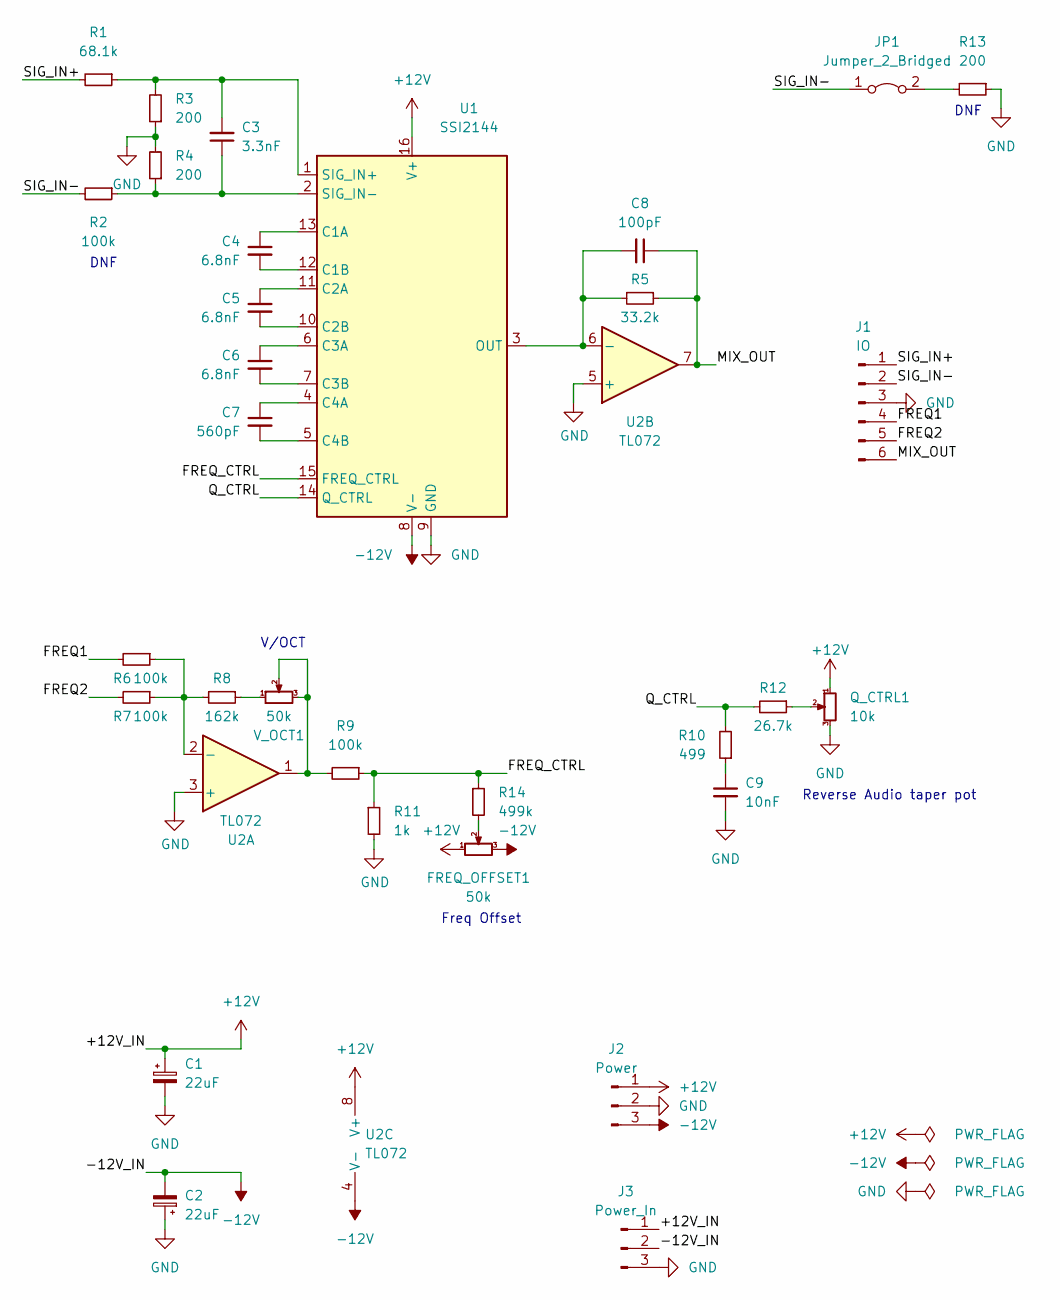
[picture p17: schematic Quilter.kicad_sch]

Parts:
C1: 22uF; CP_Elec_5x5.7; Part_Number C134798
C2: 22uF; CP_Elec_5x5.7; Part_Number C134793
C3: 3.3nF; C_0603_1608Metric_Pad1.08x0.95mm_HandSolder
C4, C5, C6: 6.8nF; C_0603_1608Metric_Pad1.08x0.95mm_HandSolder
C7: 560pF; C_0603_1608Metric_Pad1.08x0.95mm_HandSolder
C8: 100pF; C_0805_2012Metric
C9: 10nF; C_0603_1608Metric_Pad1.08x0.95mm_HandSolder
FREQ_OFFSET1: 50k; Alpha_9mm_Potentiometer_Aligned
J1: IO; PinHeader_1x06_P2.54mm_Vertical
J2: Power; PinHeader_1x03_P2.54mm_Vertical
J3: Power_In; PinHeader_1x03_P2.54mm_Vertical
JP1: Jumper_2_Bridged; SolderJumper-2_P1.3mm_Bridged_RoundedPad1.0x1.5mm
Q_CTRL1: 10k; Alpha_9mm_Potentiometer_Aligned
R1: 68.1k; R_0805_2012Metric
R2, R6, R7, R9: 100k; R_0805_2012Metric
R3, R4, R13: 200; R_0805_2012Metric
R5: 33.2k; R_0805_2012Metric
R8: 162k; R_0805_2012Metric
R10: 499; R_0805_2012Metric
R11: 1k; R_0805_2012Metric
R12: 26.7k; R_0805_2012Metric
R14: 499k; R_0805_2012Metric
U1: SSI2144; SSOP-16_3.9x4.9mm_P0.635mm
U2: TL072; SO-8_3.9x4.9mm_P1.27mm
V_OCT1: 50k; Alpha_9mm_Potentiometer_Aligned

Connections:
+12V: C1.1, FREQ_OFFSET1.1, J2.1, J3.1, Q_CTRL1.1, U1.16 (V+), U2.8 (V+)
-12V: C2.2, FREQ_OFFSET1.3, J2.3, J3.2, U1.8 (V-), U2.4 (V-)
/FREQ1: J1.4, R6.2
/FREQ2: J1.5, R7.2
/FREQ_CTRL: R9.1, R11.1, R14.1, U1.15 (FREQ_CTRL)
/MIX_OUT: C8.1, J1.6, R5.1, U2.7
/Q_CTRL: R10.2, R12.2, U1.14 (Q_CTRL)
/SIG_IN+: J1.1, R1.2
/SIG_IN-: J1.2, JP1.1 (A), R2.2
GND: C1.2, C2.1, C9.2, J1.3, J2.2, J3.3, Q_CTRL1.3, R3.1, R4.2, R11.2, R13.1, U1.9 (GND), U2.3 (+), U2.5 (+)
unnamed: C3.1, R2.1, R4.1, U1.2 (SIG_IN-)
unnamed: C3.2, R1.1, R3.2, U1.1 (SIG_IN+)
unnamed: C4.1, U1.13 (C1A)
unnamed: C4.2, U1.12 (C1B)
unnamed: C5.1, U1.11 (C2A)
unnamed: C5.2, U1.10 (C2B)
unnamed: C6.1, U1.6 (C3A)
unnamed: C6.2, U1.7 (C3B)
unnamed: C7.1, U1.4 (C4A)
unnamed: C7.2, U1.5 (C4B)
unnamed: C8.2, R5.2, U1.3 (OUT), U2.6 (-)
unnamed: C9.1, R10.1
unnamed: FREQ_OFFSET1.2, R14.2
unnamed: JP1.2 (B), R13.2
unnamed: R6.1, R7.1, R8.2, U2.2 (-)
unnamed: R8.1, V_OCT1.1
unnamed: R9.2, U2.1, V_OCT1.2, V_OCT1.3
unnamed: Q_CTRL1.2, R12.1

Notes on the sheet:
Freq Offset
DNF
V/OCT
Reverse Audio taper pot

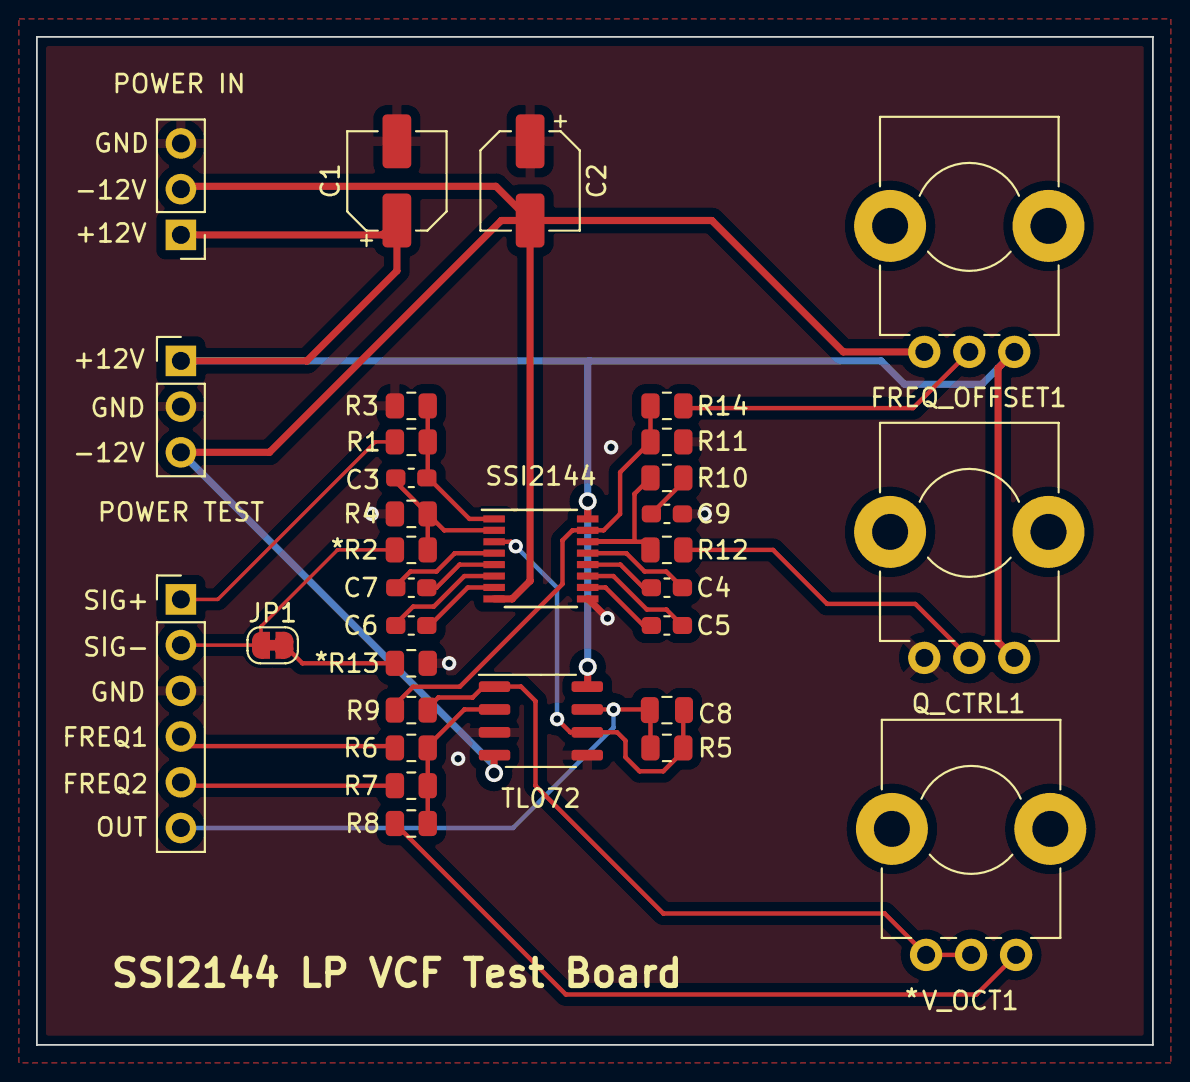
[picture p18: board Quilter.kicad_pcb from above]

Board: 2 copper layers, 62.0 x 56.0 mm, 32 parts (0 on the bottom side), 28 nets.

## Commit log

2023-02-22 Started component PCB layout
    [Quilter.kicad_pcb]
2023-02-22 First draft of component PCB routed
    [Filter_Voice.kicad_sch, Quilter.kicad_pcb, Quilter.kicad_sch]
2023-02-22 Started Controls PCB
    [Filter_Voice.kicad_sch, Quilter.kicad_pcb, Quilter.kicad_sch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]
2023-02-23 Started layout for 8HP alternative
    [Filter_Voice.kicad_sch, Quilter.kicad_pcb, Quilter.kicad_sch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]
2023-02-23 Draft of 8HP component PCB routed
    [Quilter_Components.kicad_pcb, Quilter_Components.kicad_sch]
2023-02-23 First draft routing of Controls PCB
    [Quilter_Components.kicad_pcb, Quilter_Components.kicad_sch, Quilter_Controls.kicad_pcb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]
2023-02-24 Fixed orientation of connector headers
    [Quilter_Components.kicad_pcb, Quilter_Controls.kicad_pcb]
2023-02-24 Started Panel Layout
    [Quilter_Controls.kicad_pcb, Quilter_Panel.kicad_pcb]
2023-02-24 Reorganisation of component board
    [Quilter_Components.kicad_pcb]
2023-02-24 Re-routed Controls board
    [Quilter_Components.kicad_pcb, Quilter_Components.kicad_sch, Quilter_Controls.kicad_pcb]
2023-02-26 Added all voice filter CV; panel draft done
    [Filter_Voice.kicad_sch, Quilter_Components.kicad_pcb, Quilter_Components.kicad_sch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]
2023-02-26 Updates to panel and component boards
    [Quilter_Controls.kicad_pcb, Quilter_Controls.kicad_sch, Quilter_Panel.kicad_pcb]
2023-02-27 Finished routing components and controls
    [Quilter_Components.kicad_pcb, Quilter_Components.kicad_sch, Quilter_Controls.kicad_pcb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]
2023-02-27 Schematic formatting
    [Filter_Voice.kicad_sch, Quilter_Components.kicad_pcb, Quilter_Components.kicad_sch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]
2023-03-02 Cleaned up panel and PCBs
    [BOM-Quilter_Components.csv, Filter_Voice.kicad_sch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]
2023-03-02 Updated panel and BOM
    [BOM-Quilter_Components.csv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]
2023-03-03 Added op-amp output protection resistors
    [BOM-Quilter_Components.csv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]
2023-03-04 Generated Gerbers for Production
    [CPL-Quilter_Components.csv, Quilter_Components-B_Cu.gbr, Quilter_Components-B_Mask.gbr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]
2023-03-22 Added Readme and revision notes
    [Filter_Voice.kicad_sch, Quilter.kicad_pcb, Quilter.kicad_sch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]
2023-06-26 Started adding DC blocking caps to audio outputs
    [Filter_Voice.kicad_sch, Quilter_Components.kicad_pcb, Quilter_Components.kicad_sch]
2023-07-04 Updates for v2, including dc blocking caps on output
    Also adjusted lower range of cutoff knob and tweaked various resistor values
    [BOM-Quilter_Components.csv, Filter_Voice.kicad_sch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]
2023-07-05 Reorganised components gerber location
    [CPL-Quilter_Components.csv, Quilter_Components-B_Cu.gbr, Quilter_Components-B_Mask.gbr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]
2023-07-06 Prepared v2 Controls and Components for manufacture
    [BOM-Quilter_Components.csv, Filter_Voice.kicad_sch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]
2023-07-19 Updated to Kicad 7
    [Filter_Voice.kicad_sch, Quilter_Components.kicad_sch]
